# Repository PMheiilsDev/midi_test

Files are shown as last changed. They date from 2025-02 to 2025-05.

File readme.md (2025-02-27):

# Midi Controller for Voicemeeter with rp2040

# Setting up Voicemeeter 

 - Menu -> Midi Mapping 
   - Select 'Tiny USB Device' as Input and Output 
   - Use Learn to setup the Buttons or sliders 
   - Press the 'F'-Button so that it is blue 

# Some Comments might be German and English

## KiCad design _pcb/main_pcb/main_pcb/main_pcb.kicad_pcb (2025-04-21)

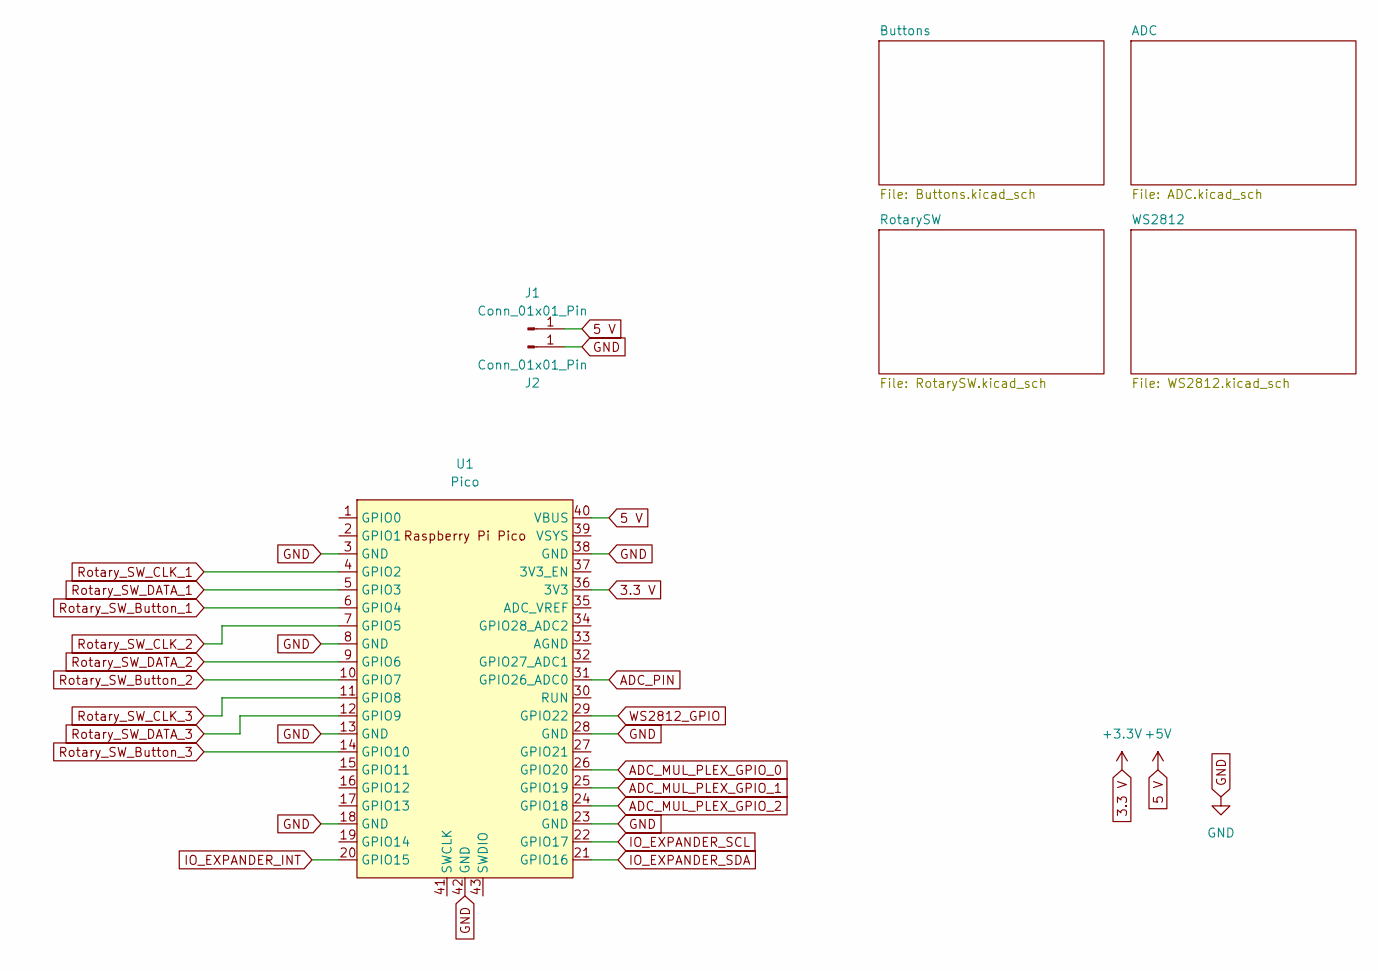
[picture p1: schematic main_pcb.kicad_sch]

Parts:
J1, J2: Conn_01x01_Pin; TestPoint_Pad_3.0x3.0mm
U1: Pico; RPi_Pico_SMD_TH

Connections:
3.3 V: U1.36 (3V3); also elsewhere on the board
5 V: J1.1, U1.40 (VBUS); also elsewhere on the board
ADC_MUL_PLEX_GPIO_0: U1.26 (GPIO20); also elsewhere on the board
ADC_MUL_PLEX_GPIO_1: U1.25 (GPIO19); also elsewhere on the board
ADC_MUL_PLEX_GPIO_2: U1.24 (GPIO18); also elsewhere on the board
ADC_PIN: U1.31 (GPIO26_ADC0); also elsewhere on the board
GND: J2.1, U1.3 (GND), U1.8 (GND), U1.13 (GND), U1.18 (GND), U1.23 (GND), U1.28 (GND), U1.38 (GND), U1.42 (GND); also elsewhere on the board
IO_EXPANDER_INT: U1.20 (GPIO15); also elsewhere on the board
IO_EXPANDER_SCL: U1.22 (GPIO17); also elsewhere on the board
IO_EXPANDER_SDA: U1.21 (GPIO16); also elsewhere on the board
Rotary_SW_Button_1: U1.6 (GPIO4); also elsewhere on the board
Rotary_SW_Button_2: U1.10 (GPIO7); also elsewhere on the board
Rotary_SW_Button_3: U1.14 (GPIO10); also elsewhere on the board
Rotary_SW_CLK_1: U1.4 (GPIO2); also elsewhere on the board
Rotary_SW_CLK_2: U1.7 (GPIO5); also elsewhere on the board
Rotary_SW_CLK_3: U1.11 (GPIO8); also elsewhere on the board
Rotary_SW_DATA_1: U1.5 (GPIO3); also elsewhere on the board
Rotary_SW_DATA_2: U1.9 (GPIO6); also elsewhere on the board
Rotary_SW_DATA_3: U1.12 (GPIO9); also elsewhere on the board
WS2812_GPIO: U1.29 (GPIO22); also elsewhere on the board

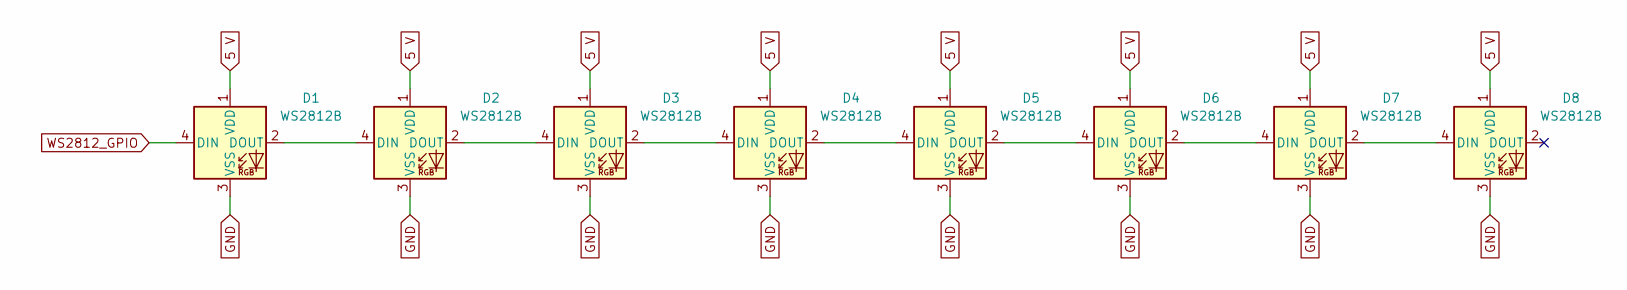
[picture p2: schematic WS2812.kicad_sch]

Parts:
D1, D2, D3, D4, D5, D6, D7, D8: WS2812B; LED_WS2812B_PLCC4_5.0x5.0mm_P3.2mm

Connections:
5 V: D1.1 (VDD), D2.1 (VDD), D3.1 (VDD), D4.1 (VDD), D5.1 (VDD), D6.1 (VDD), D7.1 (VDD), D8.1 (VDD); also elsewhere on the board
GND: D1.3 (VSS), D2.3 (VSS), D3.3 (VSS), D4.3 (VSS), D5.3 (VSS), D6.3 (VSS), D7.3 (VSS), D8.3 (VSS); also elsewhere on the board
unnamed: D1.2 (DOUT), D2.4 (DIN)
unnamed: D2.2 (DOUT), D3.4 (DIN)
unnamed: D3.2 (DOUT), D4.4 (DIN)
unnamed: D4.2 (DOUT), D5.4 (DIN)
unnamed: D5.2 (DOUT), D6.4 (DIN)
unnamed: D6.2 (DOUT), D7.4 (DIN)
unnamed: D7.2 (DOUT), D8.4 (DIN)
WS2812_GPIO: D1.4 (DIN); also elsewhere on the board

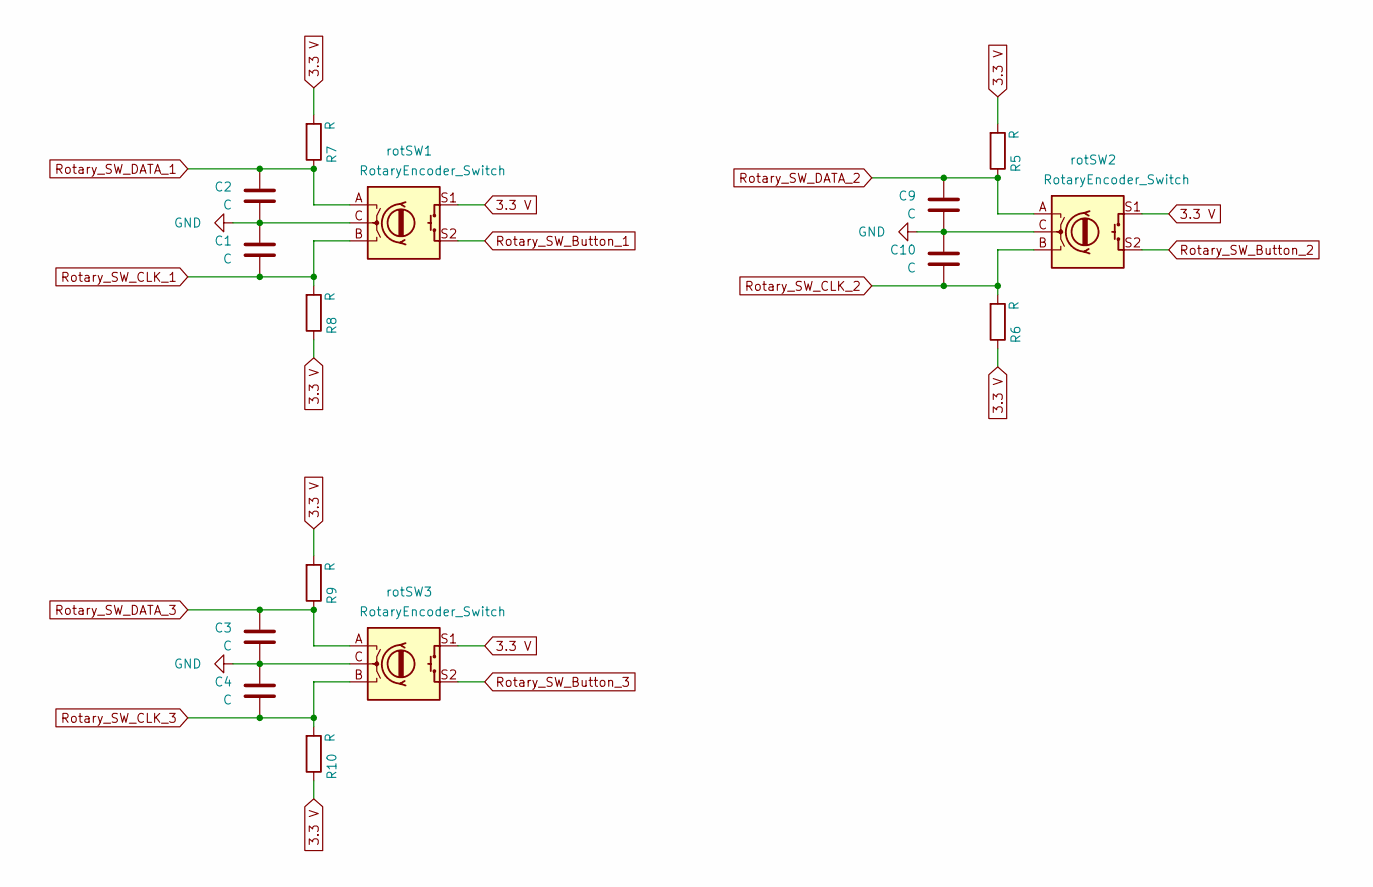
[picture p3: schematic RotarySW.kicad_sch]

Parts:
C1, C2, C3, C4, C9, C10: C; C_1206_3216Metric
R5, R6, R7, R8, R9, R10: R; R_1206_3216Metric
rotSW1, rotSW2, rotSW3: RotaryEncoder_Switch; RotaryEncoder_Alps_EC11E-Switch_Vertical_H20mm

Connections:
3.3 V: R5.2, R6.1, R7.2, R8.1, R9.2, R10.1, rotSW1.S1, rotSW2.S1, rotSW3.S1; also elsewhere on the board
GND: C1.1, C2.2, C3.2, C4.1, C9.2, C10.1, rotSW1.C, rotSW2.C, rotSW3.C; also elsewhere on the board
Rotary_SW_Button_1: rotSW1.S2; also elsewhere on the board
Rotary_SW_Button_2: rotSW2.S2; also elsewhere on the board
Rotary_SW_Button_3: rotSW3.S2; also elsewhere on the board
Rotary_SW_CLK_1: C1.2, R8.2, rotSW1.B; also elsewhere on the board
Rotary_SW_CLK_2: C10.2, R6.2, rotSW2.B; also elsewhere on the board
Rotary_SW_CLK_3: C4.2, R10.2, rotSW3.B; also elsewhere on the board
Rotary_SW_DATA_1: C2.1, R7.1, rotSW1.A; also elsewhere on the board
Rotary_SW_DATA_2: C9.1, R5.1, rotSW2.A; also elsewhere on the board
Rotary_SW_DATA_3: C3.1, R9.1, rotSW3.A; also elsewhere on the board

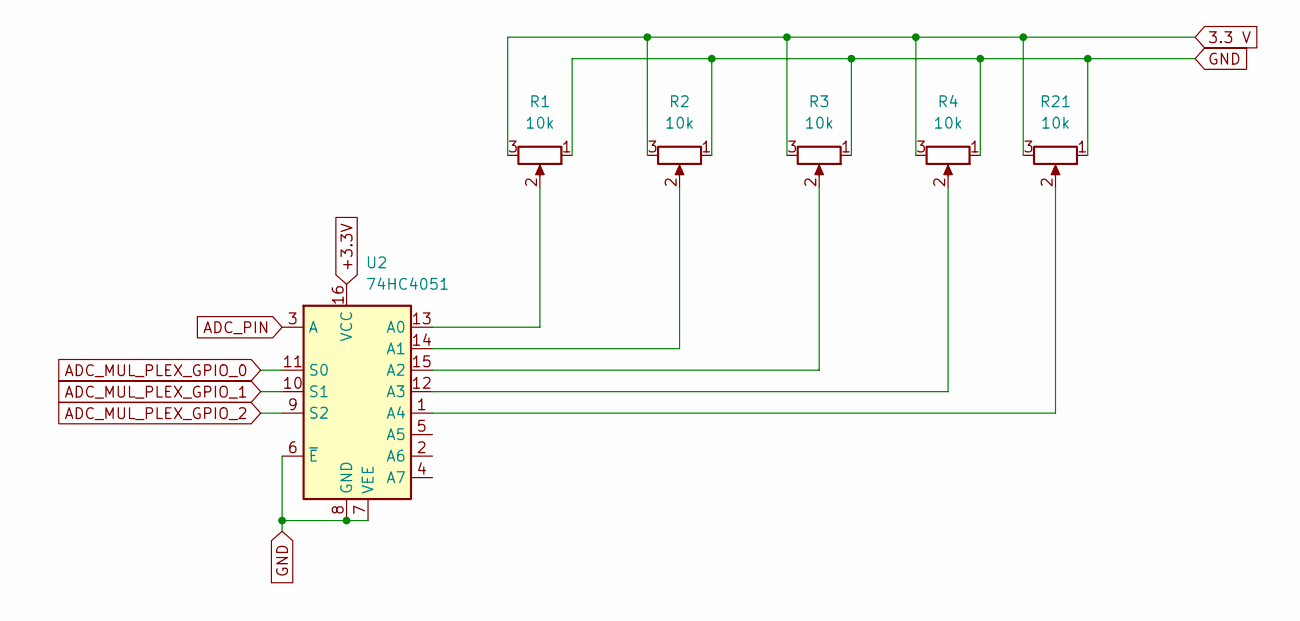
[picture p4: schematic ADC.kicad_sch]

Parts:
R1, R2, R3, R4, R21: 10k; Linear_Potentiometer
U2: 74HC4051; DIP-16_W7.62mm

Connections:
3.3 V: R1.3, R2.3, R3.3, R4.3, R21.3, U2.16 (VCC); also elsewhere on the board
ADC_MUL_PLEX_GPIO_0: U2.11 (S0); also elsewhere on the board
ADC_MUL_PLEX_GPIO_1: U2.10 (S1); also elsewhere on the board
ADC_MUL_PLEX_GPIO_2: U2.9 (S2); also elsewhere on the board
ADC_PIN: U2.3 (A); also elsewhere on the board
GND: R1.1, R2.1, R3.1, R4.1, R21.1, U2.6 (~E), U2.7 (VEE), U2.8 (GND); also elsewhere on the board
unnamed: R1.2, U2.13 (A0)
unnamed: R2.2, U2.14 (A1)
unnamed: R3.2, U2.15 (A2)
unnamed: R4.2, U2.12 (A3)
unnamed: R21.2, U2.1 (A4)

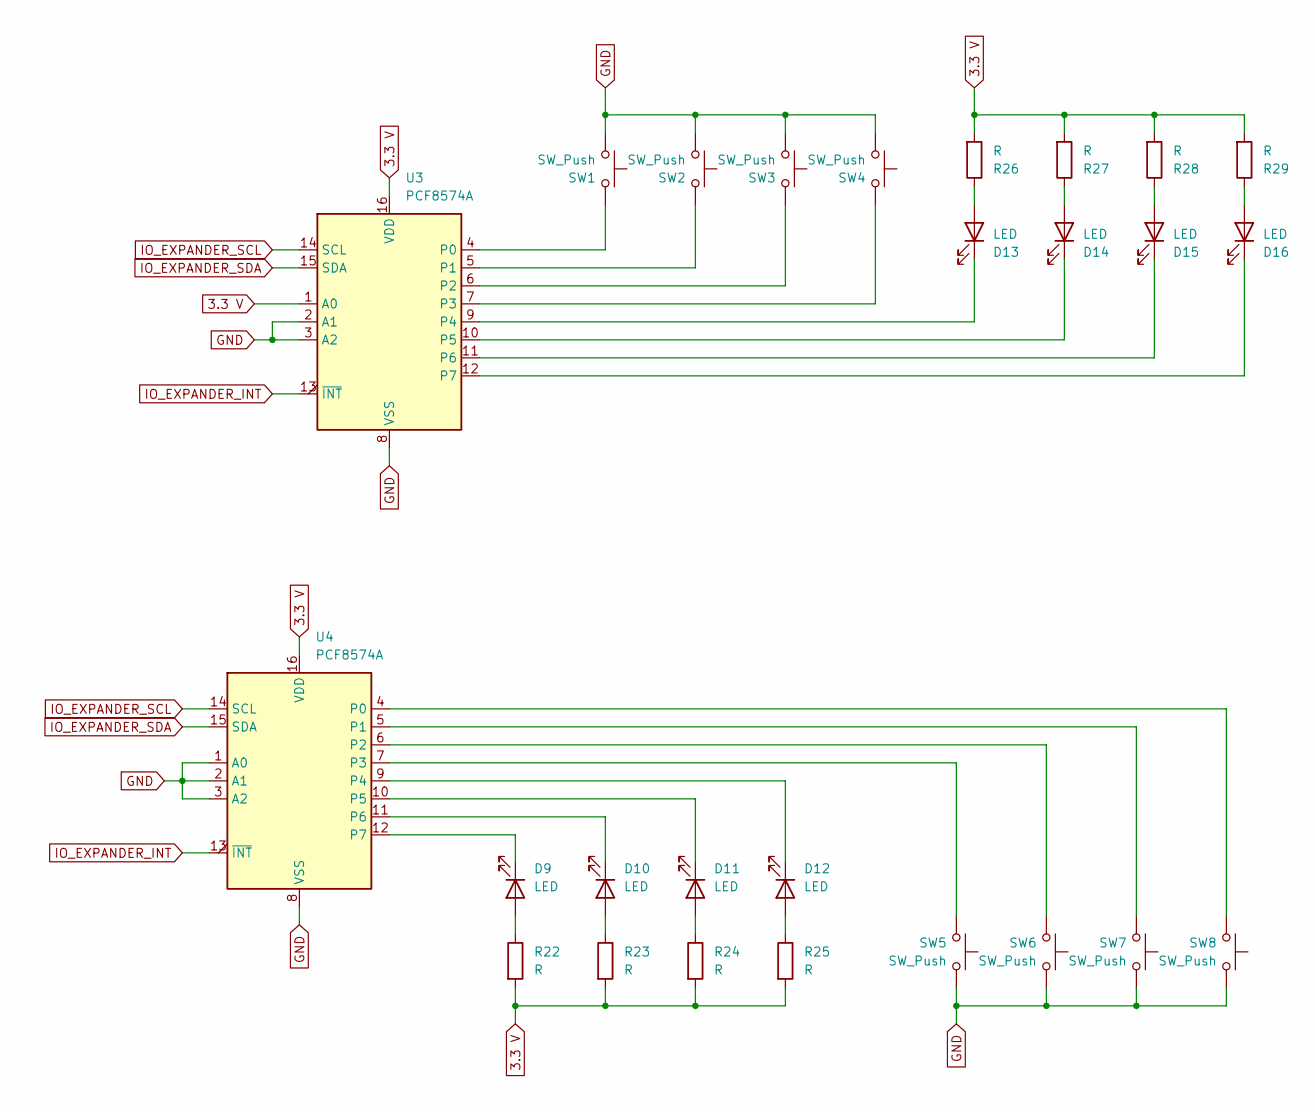
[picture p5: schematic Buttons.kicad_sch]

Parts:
D9, D10, D11, D12, D13, D14, D15, D16: LED; LED_Rectangular_W3.9mm_H1.9mm
R22, R23, R24, R25, R26, R27, R28, R29: R; L_1206_3216Metric_Pad1.22x1.90mm_HandSolder
SW1, SW2, SW3, SW4, SW5, SW6, SW7, SW8: SW_Push; SW_Cherry_MX_1.00u_Plate
U3, U4: PCF8574A; DIP-16_W7.62mm

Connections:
3.3 V: R22.2, R23.2, R24.2, R25.2, R26.2, R27.2, R28.2, R29.2, U3.1 (A0), U3.16 (VDD), U4.16 (VDD); also elsewhere on the board
GND: SW1.1, SW2.1, SW3.1, SW4.1, SW5.1, SW6.1, SW7.1, SW8.1, U3.2 (A1), U3.3 (A2), U3.8 (VSS), U4.1 (A0), U4.2 (A1), U4.3 (A2), U4.8 (VSS); also elsewhere on the board
IO_EXPANDER_INT: U3.13 (~INT), U4.13 (~INT); also elsewhere on the board
IO_EXPANDER_SCL: U3.14 (SCL), U4.14 (SCL); also elsewhere on the board
IO_EXPANDER_SDA: U3.15 (SDA), U4.15 (SDA); also elsewhere on the board
unnamed: D9.2 (A), R22.1
unnamed: D9.1 (K), U4.12 (P7)
unnamed: D10.2 (A), R23.1
unnamed: D10.1 (K), U4.11 (P6)
unnamed: D11.2 (A), R24.1
unnamed: D11.1 (K), U4.10 (P5)
unnamed: D12.2 (A), R25.1
unnamed: D12.1 (K), U4.9 (P4)
unnamed: D13.2 (A), R26.1
unnamed: D13.1 (K), U3.9 (P4)
unnamed: D14.2 (A), R27.1
unnamed: D14.1 (K), U3.10 (P5)
unnamed: D15.2 (A), R28.1
unnamed: D15.1 (K), U3.11 (P6)
unnamed: D16.2 (A), R29.1
unnamed: D16.1 (K), U3.12 (P7)
unnamed: SW1.2, U3.4 (P0)
unnamed: SW2.2, U3.5 (P1)
unnamed: SW3.2, U3.6 (P2)
unnamed: SW4.2, U3.7 (P3)
unnamed: SW8.2, U4.4 (P0)
unnamed: SW7.2, U4.5 (P1)
unnamed: SW6.2, U4.6 (P2)
unnamed: SW5.2, U4.7 (P3)

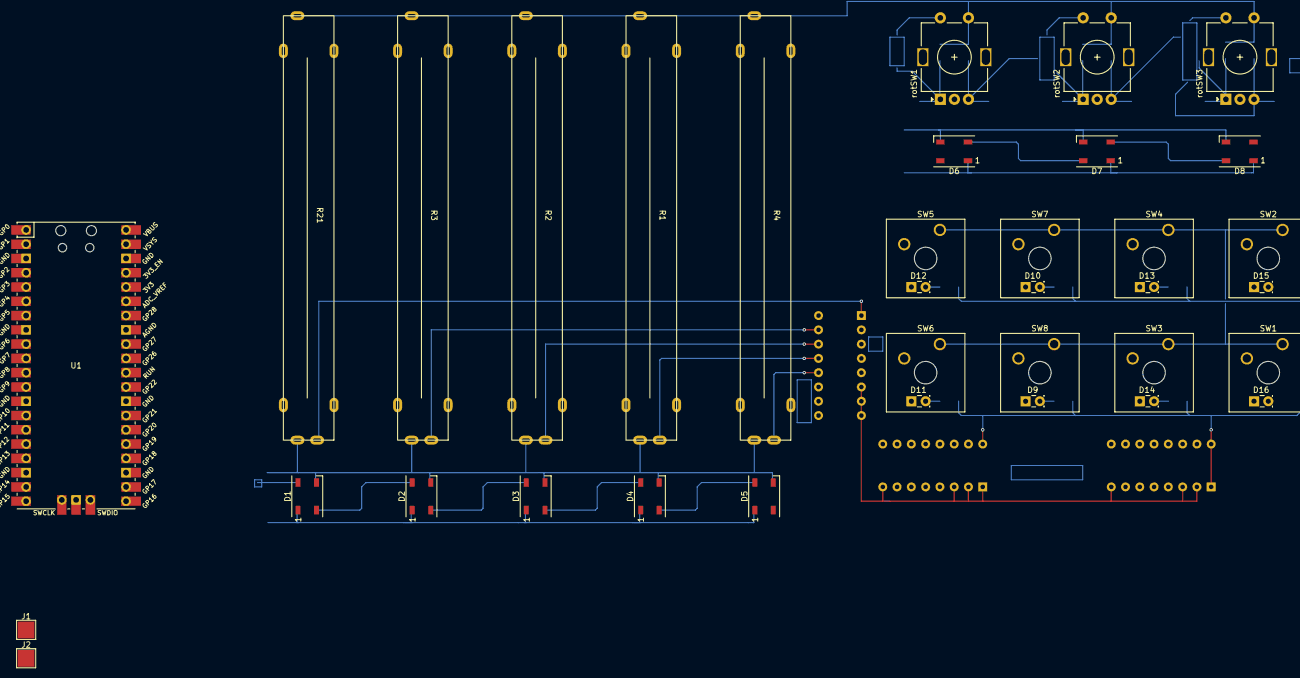
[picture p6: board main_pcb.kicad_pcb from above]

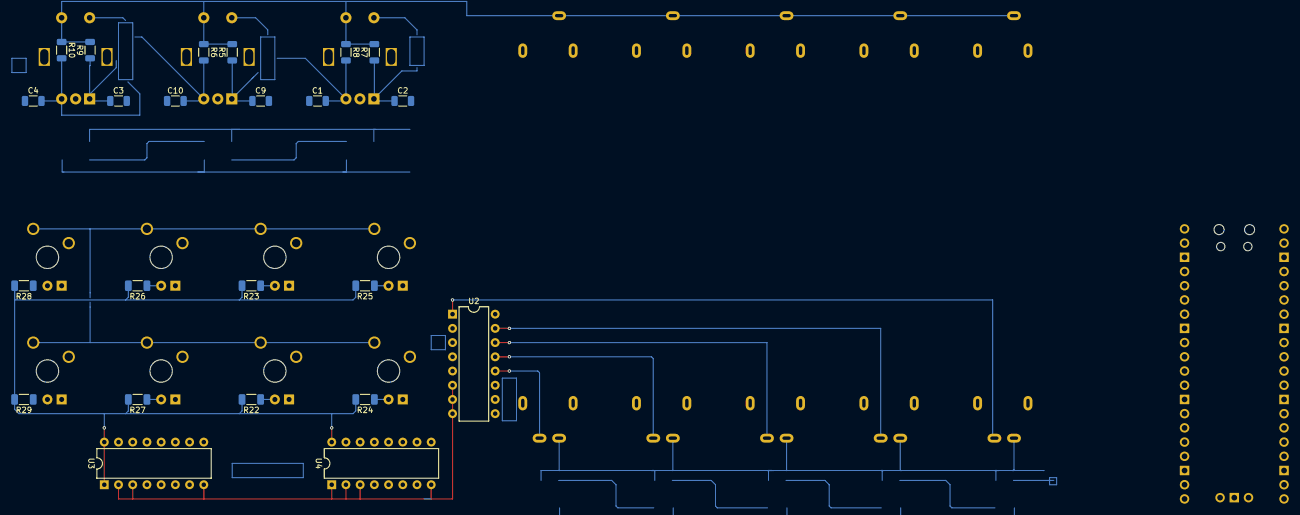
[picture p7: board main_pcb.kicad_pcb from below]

Board: 2 copper layers, 58 parts (23 on the bottom side), 56 nets.

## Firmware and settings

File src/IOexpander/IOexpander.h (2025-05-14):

#ifndef _IO_EXPANDER_H
#define _IO_EXPANDER_H

#include "hardware/i2c.h"
#include "hardware/gpio.h"

#include "main_irq_callback.h"

#define I2C_PORT i2c0 
#define I2C_SPEED 400000 

#define I2C_SDA 0
#define I2C_SCL 1 

#define IO_EXPANDER_INT_PIN 11

#define IO_EXPANDER_ADDR_0 0x20 
#define IO_EXPANDER_ADDR_1 0x21

// for the PCF8575 writing two bytes sets the state of the pins 
// if a pin is 0 then the  pins connects to GND with a small resistance
// if a pin is 1 then the pin is high impedance 

// if a pin is 1 it can be used as input 
// meaning that the read bit of that pin will be 0 if connected to GND and else 1 (as it has a pull up resistor)

//todo what I want from the functions:
//  when sending to pcf a pin is 1 when it is input or if it output and is high z 
//                      a pin is 0 when it is output and low  
// that means: pin = input | (output & high_z) 

// when reading from pcf 
//                      never connect a pin to vdd without a resistor as it is connected to GND at startup 
//                      return 0 when pin is connected to GND
//                      return 1 when pin is connected to VDD (pull up resistor or floating)
//                      return -1 when pin is output

//? ( dont make these extern no access to them from out side )
//? extern uint16_t IOexpander_pin_func;
//? extern uint16_t IOexpander_pin_func_pref;
//? 
//? extern uint16_t IOexpander_pin_state;
//? extern uint16_t IOexpander_pin_state_pref;

typedef enum 
{
    IO_EXPANDER_PIN_FUNC_OUTPUT = 0,
    IO_EXPANDER_PIN_FUNC_INPUT = 1,
}
IOexpander_pin_func_t;

typedef enum 
{
    IO_EXPANDER_PIN_OUTPUT_STATE_LOW = 0,
    IO_EXPANDER_PIN_OUTPUT_STATE_HIGH_Z = 1,
}
IOexpander_pin_output_state_t;

typedef enum 
{
    IO_EXPANDER_PIN_INPUT_STATE_LOW = 0,
    IO_EXPANDER_PIN_INPUT_STATE_HIGH = 1,
}
IOexpander_pin_input_state_t;

/// @brief initializes the IOexpander by setting all pins to high z 
/// @return true if the IOexpander is connected and false if not 
bool IOexpander_init();

void IOexpander_task();

void IO_expander_interupt_callback(uint gpio, uint32_t events);

/// @brief sets the function of a ioexpander pin 
/// @param pin_num number of the pin 0 to 15
/// @param value from enum IOexpander_pin_func 
void IOexpander_set_function( uint8_t pin_num, IOexpander_pin_func_t value );

/// @brief get the function of a pin 
/// @param pin_num number of the pin 0 to 15 
/// @return 
IOexpander_pin_func_t IOexpander_get_function( uint8_t pin_num );

/// @brief puts a value on a ioexpander pin (after calling IOexpander_update())
/// @param pin_num number of the pin 0 to 15 
/// @param value from enum IOexpander_pin_state 
void IOexpander_put( uint8_t pin_num, IOexpander_pin_output_state_t value );

/// @brief gets the value of a IO expander input pin
/// @param pin_num number of the pin 0 to 15 
/// @param force_update true to update the IO expander via I2C before reading in this function 
/// @return IOexpander_pin_input_state_t 
IOexpander_pin_input_state_t IOexpander_get( uint8_t pin_num, bool force_update );

/// @brief updates the IO expander via I2C (only if changes are done)
/// @param force force to update even if no changes where done (true recomended at first write)
/// @return true if changes where done and false if values where already correct 
bool IOexpander_write( bool force );

/// @brief updates the input pin values of the IO expander via I2C  
/// @return true if anything changed 
bool IOexpander_read();

/// @brief this is a debug function that is only planed to be used once to test for wiring 
void IOexpander_get_pin_types();


#endif

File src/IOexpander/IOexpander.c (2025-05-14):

#include "IOexpander.h"

uint16_t IOexpander_pin_func;
uint16_t IOexpander_pin_func_pref;
uint16_t IOexpander_pin_state;
uint16_t IOexpander_pin_state_pref;

bool IOexpander_int = false;

bool IOexpander_init(void)
{
    i2c_init(I2C_PORT, I2C_SPEED);
    gpio_set_function(I2C_SDA, GPIO_FUNC_I2C);
    gpio_set_function(I2C_SCL, GPIO_FUNC_I2C);
    gpio_pull_up(I2C_SDA);
    gpio_pull_up(I2C_SCL);

    IOexpander_pin_func = 0xFFFF;
    IOexpander_pin_state = 0xFFFF;

    // Test if PCF8575 is connected
    uint8_t data[2] = {0xFF, 0xFF};
    int result_0 = i2c_write_blocking(I2C_PORT, IO_EXPANDER_ADDR_0, &data[0], 1, false);
    int result_1 = i2c_write_blocking(I2C_PORT, IO_EXPANDER_ADDR_1, &data[1], 1, false);

    if ( (result_0 != PICO_ERROR_GENERIC) && (result_1 != PICO_ERROR_GENERIC) )
    {
        gpio_init(IO_EXPANDER_INT_PIN);
        gpio_set_dir(IO_EXPANDER_INT_PIN, GPIO_IN);
        gpio_pull_up(IO_EXPANDER_INT_PIN);


        gpio_set_irq_enabled_with_callback(IO_EXPANDER_INT_PIN, GPIO_IRQ_EDGE_RISE | GPIO_IRQ_EDGE_FALL, true, &main_interupt_callback);
    }

    // IOexpander_set_function( 5, IO_EXPANDER_PIN_FUNC_OUTPUT );

    return ((result_0 != PICO_ERROR_GENERIC) && (result_1 != PICO_ERROR_GENERIC)); 
}


void IO_expander_interupt_callback(uint gpio, uint32_t events)
{
    if( (gpio == IO_EXPANDER_INT_PIN) && (events & GPIO_IRQ_EDGE_RISE | GPIO_IRQ_EDGE_FALL) )
    {
        IOexpander_int = true;
    }
    return;
}


void IOexpander_task()
{
    IOexpander_write(false);
    
    if ( IOexpander_int )
    {
        IOexpander_read();
        IOexpander_int = false;
    }
}


void IOexpander_set_function( uint8_t pin_num, IOexpander_pin_func_t value )
{
    IOexpander_pin_func = (IOexpander_pin_func & ~(1 << pin_num)) | ((value & 1) << pin_num);

}


void IOexpander_put( uint8_t pin_num, IOexpander_pin_output_state_t value )
{
    IOexpander_pin_state = (IOexpander_pin_state & ~(1 << pin_num)) | ((value & 1) << pin_num);
    
}


IOexpander_pin_func_t IOexpander_get_function( uint8_t pin_num )
{
    // this does not use the enums just leave it this way 
    return (IOexpander_pin_func >> pin_num) & 1; 
}

static uint8_t reverse_bits(uint8_t byte)
{
    byte = (byte & 0xF0) >> 4 | (byte & 0x0F) << 4;
    byte = (byte & 0xCC) >> 2 | (byte & 0x33) << 2;
    byte = (byte & 0xAA) >> 1 | (byte & 0x55) << 1;
    return byte;
}

bool IOexpander_write( bool force )
{
    if ( force || ( IOexpander_pin_func != IOexpander_pin_func_pref ) || ( IOexpander_pin_state != IOexpander_pin_state_pref ) )
    {
        // if the pin is input set to 1 or if the pin is highz set to 1 
        uint8_t data [2];
        data[0] = ( ( IOexpander_pin_func | (~IOexpander_pin_func & IOexpander_pin_state) ) >> 0 ) & 0xFF;
        data[1] = ( ( IOexpander_pin_func | (~IOexpander_pin_func & IOexpander_pin_state) ) >> 8 ) & 0xFF;

        i2c_write_blocking(I2C_PORT, IO_EXPANDER_ADDR_0, &data[0], 1, false);
        i2c_write_blocking(I2C_PORT, IO_EXPANDER_ADDR_1, &data[1], 1, false);
        
        IOexpander_pin_func_pref = IOexpander_pin_func;
        IOexpander_pin_state_pref = IOexpander_pin_state;

        return true;
    }
    return false;
}


bool IOexpander_read()
{
    uint8_t data [2];
    i2c_read_blocking(I2C_PORT, IO_EXPANDER_ADDR_0, &data[0], 1, false);
    i2c_read_blocking(I2C_PORT, IO_EXPANDER_ADDR_1, &data[1], 1, false);

    IOexpander_pin_state = ((data[1] << 8) | data[0]) /*& IOexpander_pin_func*/;

    bool ret = IOexpander_pin_state != IOexpander_pin_state_pref;

    IOexpander_pin_state_pref = IOexpander_pin_state;

    return ret;
}


IOexpander_pin_input_state_t IOexpander_get( uint8_t pin_num, bool force_update )
{
    if ( force_update )
    {
        IOexpander_read();
    }


    bool value = IOexpander_pin_state >> pin_num & 1;
    
    return value;
}

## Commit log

2024-11-21 working adc to pwm ; not working in voice meeter
2025-02-09 Button init
2025-02-09 Button doing nothing yet
2025-02-09 uart debugging not working
2025-02-14 refresh buttons not scaling
2025-02-14 adding input device change message
2025-02-14 device selection working
2025-02-14 clear button
2025-02-14 made it bolt
2025-02-14 Disconnect Buttons
2025-02-28 moved adc handler
2025-02-28 moved led functions
2025-02-28 changed to led handler
2025-02-28 changed adc scaling
2025-03-02 led setup functions
2025-03-02 extended to more than one rot sw switch with AI
2025-03-03 gpio to adc channel
2025-03-07 removed pwm pin
2025-03-07 changed to work with multiple adc pins
2025-03-07 added adc multiplexer support initialisation
2025-03-08 testing how long a loop takes .5 ms without adc sleep time
2025-03-08 added kiCAD Project
    [main_pcb.kicad_pcb, main_pcb.kicad_sch]
2025-03-08 added lib for mx switches
2025-03-08 added own footprint lib for potentiometer
2025-03-08 automatic changes by kicad
2025-03-08 added pi pico footprint library
2025-03-08 added pi pico symbol from lib
2025-03-08 changes to pcb
    [ADC.kicad_sch, main_pcb.kicad_pcb, main_pcb.kicad_sch]
2025-03-08 added io expander and rotSW only ws2812 missing
    [Buttons.kicad_sch, RotarySW.kicad_sch, main_pcb.kicad_sch]
2025-03-09 added WS2812
    [WS2812.kicad_sch, main_pcb.kicad_sch]
2025-03-09 for now the last commit for pcb as buying pcb is too expensive
    [ADC.kicad_sch, WS2812.kicad_sch, main_pcb.kicad_pcb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]
2025-03-11 not working maybe bit order wrong ??
    [IOexpander.c, midi_test.c]
2025-03-11 all pins OUTPUT working fine, exept the one o was testing with (maybe i broke pin P10 ???)
    [IOexpander.c, midi_test.c]
2025-03-11 input not working as planned
    [IOexpander.c, midi_test.c]
2025-03-11 seams to be working as expected only P10(pin 8) not working properly
    [IOexpander.c, midi_test.c]
2025-03-11 working button toggleing a led
2025-03-11 removed error state from get so now working as gpio_put( not gpio_get )
    [IOexpander.c, IOexpander.h, midi_test.c]
2025-03-12 adc via mul plex working
2025-03-12 io exp and adc working together without i2c never returning
2025-03-12 adc working with three via mul plex and one directly
2025-03-12 added leds to io expander
    [ADC.kicad_sch, Buttons.kicad_sch]
2025-03-12 io expander working via midi in voicemeeter but it shows some strange behaivior as if voicemeeter tryes to fix the software change when state is changed from voice meeter
    [midi_test.c]
2025-03-16 changed adc mapping
2025-03-21 hardware prototype working ( rot sw and io expander )
2025-03-30 feedback for buttons also working
2025-03-30 this removes all the flickering from the adc result that is sent
2025-03-31 this does work but has the problem of skipping one step when actually wanting to change the direction so when the manted movement is 100->101->100 the last 100 is not sent as it was there in the last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
    [adc_handler.c, adc_handler.h]
2025-03-31 this seams to have fixed all the adc flickering problems
    [adc_handler.c, adc_handler.h, ws2812_handler.c]
2025-04-20 rewired rot sw curcits to new plans reduced to only 3
    [RotarySW.kicad_sch]
2025-04-20 removed 4th rot sw from pico
    [main_pcb.kicad_sch]
2025-04-20 removed all pcb plans
    [main_pcb.kicad_pcb]
2025-04-20 moved to two pcf8574 instead of pcf8575
    [Buttons.kicad_sch]
2025-04-20 bauteile sortiert
    [main_pcb.kicad_pcb]
2025-04-20 both pcf an in and out
    [Buttons.kicad_sch]
2025-04-20 positoned all but pico
    [main_pcb.kicad_pcb]
2025-04-20 changed ICs to THT
    [ADC.kicad_sch, Buttons.kicad_sch]
2025-04-20 position of pico not really clear
    [main_pcb.kicad_pcb, main_pcb.kicad_sch]
2025-04-21 changed 3.3 V and 0 V so that it is correct
    [ADC.kicad_sch]
2025-04-21 switches the i2c addresses so that its better on pcb
    [Buttons.kicad_sch]
2025-04-21 alle anderen Verbindungen mit Lackdraht
    [main_pcb.kicad_pcb]
2025-04-30 changed to work with two pcf8574 instead of one pcf8575 the solution always i2c's to both addresses that could be reduced when writing not when listening though
2025-04-30 changed to test all the buttons (hardware working)
2025-04-30 this makes all leds blink
2025-05-03 changed the pins to fit possible hardware
    [main_pcb.kicad_sch]
2025-05-14 i believe to have found the correct pin combinations manually
    [IOexpander.c, IOexpander.h, midi_test.c]
2025-05-14 all the ioexpander buttons and pins work with each other and are sent via midi
2025-05-15 this works with the buttons when turning on and off from button then on from software it is not send seams to be a voicemeeter error
2025-08-15 fixed slider to led mapping
    [ws2812_handler.c]
2025-08-15 this removes the flickering problem i had
    [adc_handler.c]
2025-08-15 use changed to deside if has to be send add inverted config function
    [rotarty_switch.c]
